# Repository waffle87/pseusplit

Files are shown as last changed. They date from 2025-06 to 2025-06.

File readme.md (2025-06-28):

# Pseusplit

A pseudo-split keyboard with a trackpad or LCD display and per-key RGB

pcb_top

pcb_bottom

## Hardware Specifics
This keyboard uses an integrated STM32G0B1 microcontroller fit with a single push button switch<sup>[1](#references)</sup>, and USB-C. It also features a dedicated IS31FL3733 RGB Matrix driver to alleviate processing power from the primary MCU for LCD drawing, or other tasks.

## Ordering
The following instructions will be for [JLCPCB](jlcpcb.com), but should generally apply to most PCB manufacturers. The Gerber files in this repository include:
- [**pcb_gerbers.zip**](production/pcb_gerbers.zip): Main PCB
- [**plate_gerbers.zip**](production/plate_gerbers.zip): Switch Plate PCB<sup>*</sup>
- [**back_gerbers.zip**](production/back_gerbers.zip): Backplate PCB

* The switch plate PCB is designed for a single half of the keyboard (and is reversible), meaning ordering a quantity of 10 will be enough to cover 5 keyboards.

1. Upload the appropriate Gerber files described above
2. Set PCB quantity and colour as desired
3. For PCB assembly, choose **Economic** PCBA type and **Bottom Side** for assembly side
4. Upload the [BOM](production/bom.csv) and [CPL](production/positions.csv) files
5. Ensure the correct components have been selected, and all are in stock. An effort has been made to choose as few extended components as possible, but this is not possible for some.
6. Give a quick look at the component placement and make sure nothing looks wildly wrong. It is normal for some components to be shown oriented incorrectly or not quite where they belong. The PCB reviewers will usually correct this without issue.

### Additional Components
For optional components to be installed by hand:
| Item | Quantity | Remarks |
|---|---|---|
| 6028 RGB LEDs ([Alibaba](https://www.alibaba.com/product-detail/smd-6028-RGB-led-diode-for_60637386884.html)) | 36 | Unforunately, LEDs matching this pinout are rather difficult to find, and are not carried by LCSC. |
| 4mm M2 Screws | 8 | Used for mounting PCB to plate case. Length does not have to be exact. |
| 6mm M2 Standoffs | 4 | Used for mounting PCB to plate case. Ensure maximum diameter is no greater than 4mm. |
| 240x240 LCD ([ST7789](https://www.adafruit.com/product/3787)) | 1<sup>*</sup> | Other displays with same pinout and dimensions (no larger than 40x43mm) will work. |
| Azoteq Trackpad ([TPS43](https://www.mouser.com/ProductDetail/Azoteq/TPS43-201A-B?qs=HXFqYaX1Q2x%252BNkQCZlM0ug%3D%3D)) | 1<sup>*</<sup> | Installed via soldering wires to appropriate display header pins. |
| MX Switches | 36 | Pick your favourite switches! |

* Trackpad and LCD is either/or. Both cannot be installed at the same time.

## Assembly Instructions
These steps assume you already have an assembled PCB and are installing switches, trackpad, etc. If you are hand-assembling the PCBs with all components, the [interactive BOM](https://html-preview.github.io/?url=https://github.com/waffle87/pseusplit/blob/master/ibom.html) will be handy.

1. **Compile and flash firmware.** This assumes a local QMK build environment has already been setup. Firmware sources can be found [here](https://git.pngu.org/qmk_me/keyboards/pseusplit). Enter bootloader by holding the reset button while plugging PCB in. Flash firmware using `qmk flash` or QMK Toolbox.
2. **Ensure the keyboard is functional** by shorting switch footprint pins with metal tweezers. This should output keypresses on the computer.
3. **Install LCD display if desired.** Solder the 12 pin header to the labeled footprint on the PCB and solder display to the header. In the firmware, enable the Quantum Painter feature and disable the Pointing Device feature if necessary.
4. **Install Azoteq trackpad if desired.** Solder wires from the pins on the trackpad to the appropriate pins on the 12 pin header. Refer to schematic for specifics. In the firmware, enable the Pointing Device feature and disable the Quantum Painter feature if necessary.
5. **Install switches** by inserting a few switches into the switch plate (corners/middle), and then solder to PCB. Fill in rest of switches, testing as you go.
6. **Assemble plate case**. Insert the M2 screws into the back plate and affix standoffs to screws. Place PCB + Plate onto standoffs and install remaining 4 screws.

## References
1. [A single-push reset circuit for STM32](https://acheronproject.com/reset_article_1/reset_article_1)
2. Relevant datasheets

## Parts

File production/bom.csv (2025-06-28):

Designator | Footprint | Quantity | Value | LCSC Part #
C1, C2, C4, C6 | 0805 | 4 | 0.47u | C13967
C10, C11 | 0805 | 2 | 1u | C28323
C12, C9 | 0805 | 2 | 4.7n | C1744
C13 | 0805 | 1 | 10u | C15850
C14, C16 | 0805 | 2 | 100n | C28233
C17, C18 | 0805 | 2 | 4.7u | C1779
C3, C5, C7 | 0805 | 3 | 0.1u | C49678
C8 | CP_EIA-3216-18_Kemet-A | 1 | 22u | C11366
D1, D10, D11, D12, D13, D14, D15, D16, D17, D18, D19, D2, D20, D21, D22, D23, D24, D25, D26, D27, D28, D29, D3, D30, D31, D32, D33, D34, D38, D39, D4, D5, D6, D7, D8, D9 | D_SOD-123 | 36 | D_45deg | C81598
D37 | D_SOD-123 | 1 | 1N4148 | C81598
D40 | 0805 | 1 | LED | C2297
F1 | 1206 | 1 | 500mA | C70070
J1 | USB_C_Receptacle_HRO_TYPE-C-31-M-12 | 1 | USB_C_Receptacle_USB2.0_14P | C165948
Q1 | SOT-23 | 1 | DTC123J | C406040
R1 | 0805 | 1 | 20k | C4328
R11, R2 | 0805 | 2 | 100k | C149504
R12, R7, R8 | 0805 | 3 | 5.1k | C27834
R3 | 0805 | 1 | 10k | C17414
R4, R5 | 0805 | 2 | 2k | C17604
R6 | 0805 | 1 | 1M | C17514
SW1 | SW_SPST_SKQG_WithStem | 1 | Reset_SW | C318884
U1 | QFN-48-1EP_6x6mm_P0.4mm_EP4.2x4.2mm | 1 | IS31FL3733-QF | C506251
U2 | SOT-23-3 | 1 | XC6206PxxxMR | C5446
U4 | LQFP-48_7x7mm_P0.5mm | 1 | STM32G0B1CBTx | C2847904
U5 | SOT-23-6-routable | 1 | SRV05-4 | C558418

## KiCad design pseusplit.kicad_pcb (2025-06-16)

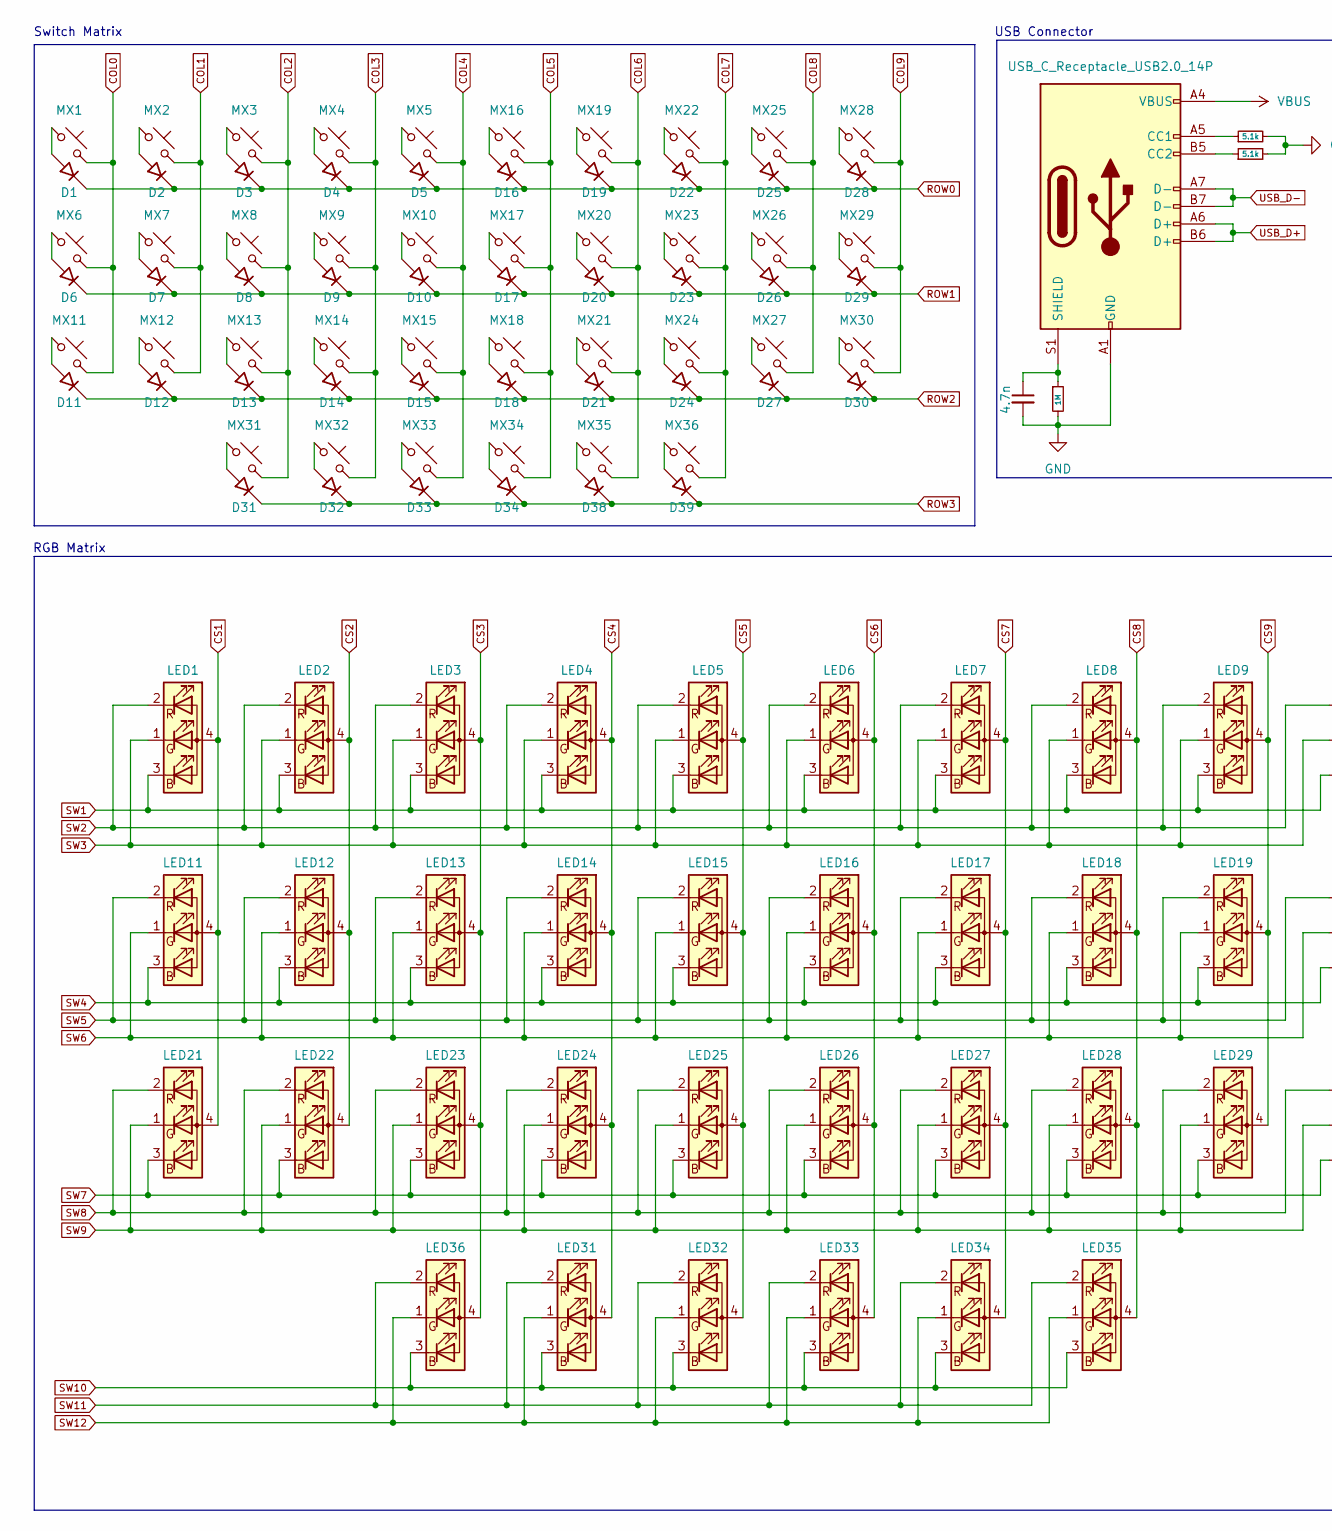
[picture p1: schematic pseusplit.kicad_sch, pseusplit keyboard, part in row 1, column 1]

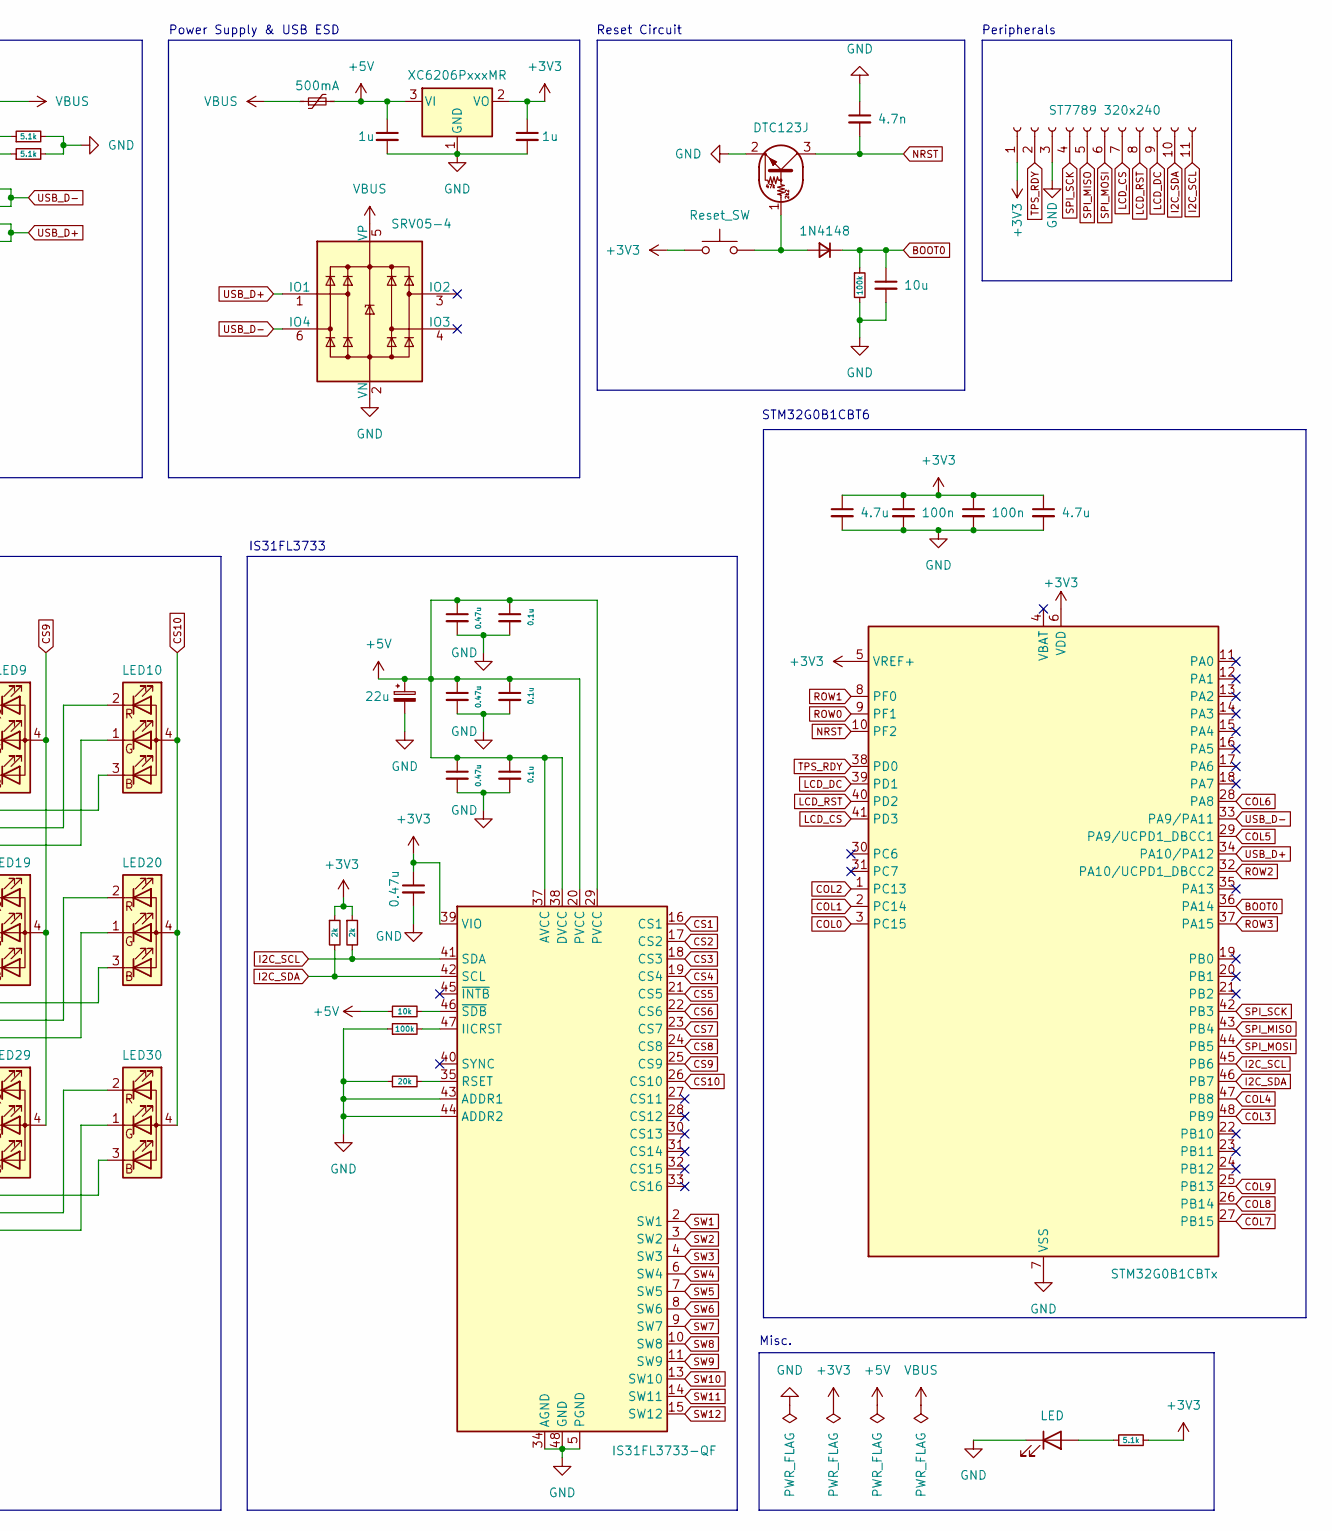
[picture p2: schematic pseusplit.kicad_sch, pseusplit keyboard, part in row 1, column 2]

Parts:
C1, C2, C4, C6: 0.47u; C_0805_2012Metric; MPN C13967
C3, C5, C7: 0.1u; C_0805_2012Metric; MPN C49678
C8: 22u; C_0805_2012Metric; MPN C45783
C9, C12: 4.7n; C_0805_2012Metric; MPN C1744
C10, C11: 1u; C_0805_2012Metric; MPN C28323
C13: 10u; C_0805_2012Metric; MPN C15850
C14, C16: 100n; C_0805_2012Metric; MPN C28233
C17, C18: 4.7u; C_0805_2012Metric; MPN C1779
D1, D2, D3, D4, D5, D6, D7, D8, D9, D10, D11, D12, D13, D14, D15, D16, D17, D18, D19, D20, D21, D22, D23, D24, D25, D26, D27, D28, D29, D30, D31, D32, D33, D34, D38, D39: D_45deg; D_SOD-123; MPN C81598
D37: 1N4148; D_SOD-123; MPN C81598
D40: LED; LED_0805_2012Metric; MPN C2297
F1: 500mA; Fuse_1206_3216Metric; MPN C2830238
J1: USB_C_Receptacle_USB2.0_14P; USB_C_Receptacle_HRO_TYPE-C-31-M-12; MPN C165948
J3: ST7789 320x240; PinHeader_1x11_P2.54mm_Vertical
LED1, LED2, LED3, LED4, LED5, LED6, LED7, LED8, LED9, LED10, LED11, LED12, LED13, LED14, LED15, LED16, LED17, LED18, LED19, LED20, LED21, LED22, LED23, LED24, LED25, LED26, LED27, LED28, LED29, LED30, LED31, LED32, LED33, LED34, LED35, LED36: MX_LED_6028R; LED_MX_6028R; MPN C183826
MX1: Q; SW_MX_1u
MX2: W; SW_MX_1u
MX3: E; SW_MX_1u
MX4: R; SW_MX_1u
MX5: T; SW_MX_1u
MX6: A; SW_MX_1u
MX7: S; SW_MX_1u
MX8: D; SW_MX_1u
MX9: F; SW_MX_1u
MX10: G; SW_MX_1u
MX11: Z; SW_MX_1u
MX12: X; SW_MX_1u
MX13: C; SW_MX_1u
MX14: V; SW_MX_1u
MX15: B; SW_MX_1u
MX16: Y; SW_MX_1u
MX17: H; SW_MX_1u
MX18: N; SW_MX_1u
MX19: U; SW_MX_1u
MX20: J; SW_MX_1u
MX21: M; SW_MX_1u
MX22: I; SW_MX_1u
MX23: K; SW_MX_1u
MX24: ,; SW_MX_1u
MX25: O; SW_MX_1u
MX26: L; SW_MX_1u
MX27: .; SW_MX_1u
MX28: P; SW_MX_1u
MX29: ;; SW_MX_1u
MX30: /; SW_MX_1u
MX31: T1; SW_MX_1u
MX32: T2; SW_MX_1u
MX33: T3; SW_MX_1u
MX34: T4; SW_MX_1u
MX35: T5; SW_MX_1u
MX36: T6; SW_MX_1u
Q1: DTC123J; SOT-23; MPN C20616358
R1: 20k; R_0805_2012Metric; MPN C4328
R2, R11: 100k; R_0805_2012Metric; MPN C149504
R3: 10k; R_0805_2012Metric; MPN C17414
R4, R5: 2k; R_0805_2012Metric; MPN C17604
R6: 1M; R_0805_2012Metric; MPN C17514
R7, R8, R12: 5.1k; R_0805_2012Metric; MPN C27834
SW1: Reset_SW; SW_SPST_SKQG_WithStem; MPN C318884
U1: IS31FL3733-QF; QFN-48-1EP_6x6mm_P0.4mm_EP4.2x4.2mm; MPN C506251
U2: XC6206PxxxMR; SOT-23-3; MPN C5446
U4: STM32G0B1CBTx; LQFP-48_7x7mm_P0.5mm; MPN C2847904
U5: SRV05-4; SOT-23-6-routable; MPN C558418

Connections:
+3V3: C1.1, C11.1, C14.1, C16.1, C17.1, C18.1, J3.1, R4.1, R5.1, R12.2, SW1.1, U1.39 (VIO), U2.2 (VO), U4.5 (VREF+), U4.6 (VDD)
+5V: C2.1, C3.1, C4.1, C5.1, C6.1, C7.1, C8.1, C10.1, F1.2, R3.1, U1.20 (PVCC), U1.29 (PVCC), U1.37 (AVCC), U1.38 (DVCC), U2.3 (VI)
BOOT0: C13.1, D37.1 (K), R11.1, U4.36 (PA14)
COL0: MX1.2, MX6.2, MX11.2, U4.3 (PC15)
COL1: MX2.2, MX7.2, MX12.2, U4.2 (PC14)
COL2: MX3.2, MX8.2, MX13.2, MX31.2, U4.1 (PC13)
COL3: MX4.2, MX9.2, MX14.2, MX32.2, U4.48 (PB9)
COL4: MX5.2, MX10.2, MX15.2, MX33.2, U4.47 (PB8)
COL5: MX16.2, MX17.2, MX18.2, MX34.2, U4.29 (PA9/UCPD1_DBCC1)
COL6: MX19.2, MX20.2, MX21.2, MX35.2, U4.28 (PA8)
COL7: MX22.2, MX23.2, MX24.2, MX36.2, U4.27 (PB15)
COL8: MX25.2, MX26.2, MX27.2, U4.26 (PB14)
COL9: MX28.2, MX29.2, MX30.2, U4.25 (PB13)
CS1: LED1.4 (A), LED11.4 (A), LED21.4 (A), U1.16 (CS1)
CS2: LED2.4 (A), LED12.4 (A), LED22.4 (A), U1.17 (CS2)
CS3: LED3.4 (A), LED13.4 (A), LED23.4 (A), LED36.4 (A), U1.18 (CS3)
CS4: LED4.4 (A), LED14.4 (A), LED24.4 (A), LED31.4 (A), U1.19 (CS4)
CS5: LED5.4 (A), LED15.4 (A), LED25.4 (A), LED32.4 (A), U1.21 (CS5)
CS6: LED6.4 (A), LED16.4 (A), LED26.4 (A), LED33.4 (A), U1.22 (CS6)
CS7: LED7.4 (A), LED17.4 (A), LED27.4 (A), LED34.4 (A), U1.23 (CS7)
CS8: LED8.4 (A), LED18.4 (A), LED28.4 (A), LED35.4 (A), U1.24 (CS8)
CS9: LED9.4 (A), LED19.4 (A), LED29.4 (A), U1.25 (CS9)
CS10: LED10.4 (A), LED20.4 (A), LED30.4 (A), U1.26 (CS10)
GND: C1.2, C2.2, C3.2, C4.2, C5.2, C6.2, C7.2, C8.2, C9.2, C10.2, C11.2, C12.1, C13.2, C14.2, C16.2, C17.2, C18.2, D40.1 (K), J1.A1 (GND), J1.A12 (GND), J1.B1 (GND), J1.B12 (GND), J3.3, Q1.2 (E), R1.1, R2.1, R6.2, R7.2, R8.2, R11.2, U1.5 (PGND), U1.12 (PGND), U1.34 (AGND), U1.43 (ADDR1), U1.44 (ADDR2), U1.48 (GND), U1.49 (GND), U2.1 (GND), U4.7 (VSS), U5.2 (VN)
I2C_SCL: J3.11, R5.2, U1.41 (SDA), U4.45 (PB6)
I2C_SDA: J3.10, R4.2, U1.42 (SCL), U4.46 (PB7)
LCD_CS: J3.7, U4.41 (PD3)
LCD_DC: J3.9, U4.39 (PD1)
LCD_RST: J3.8, U4.40 (PD2)
NRST: C12.2, Q1.3 (C), U4.10 (PF2)
unnamed: D1.2 (A), MX1.1
unnamed: D2.2 (A), MX2.1
unnamed: D3.2 (A), MX3.1
unnamed: D4.2 (A), MX4.1
unnamed: D5.2 (A), MX5.1
unnamed: D6.2 (A), MX6.1
unnamed: D7.2 (A), MX7.1
unnamed: D8.2 (A), MX8.1
unnamed: D9.2 (A), MX9.1
unnamed: D10.2 (A), MX10.1
unnamed: D11.2 (A), MX11.1
unnamed: D12.2 (A), MX12.1
unnamed: D13.2 (A), MX13.1
unnamed: D14.2 (A), MX14.1
unnamed: D15.2 (A), MX15.1
unnamed: D16.2 (A), MX16.1
unnamed: D17.2 (A), MX17.1
unnamed: D18.2 (A), MX18.1
unnamed: D19.2 (A), MX19.1
unnamed: D20.2 (A), MX20.1
unnamed: D21.2 (A), MX21.1
unnamed: D22.2 (A), MX22.1
unnamed: D23.2 (A), MX23.1
unnamed: D24.2 (A), MX24.1
unnamed: D25.2 (A), MX25.1
unnamed: D26.2 (A), MX26.1
unnamed: D27.2 (A), MX27.1
unnamed: D28.2 (A), MX28.1
unnamed: D29.2 (A), MX29.1
unnamed: D30.2 (A), MX30.1
unnamed: D31.2 (A), MX31.1
unnamed: D32.2 (A), MX32.1
unnamed: D33.2 (A), MX33.1
unnamed: D34.2 (A), MX34.1
unnamed: D37.2 (A), Q1.1 (B), SW1.2
unnamed: D38.2 (A), MX35.1
unnamed: D39.2 (A), MX36.1
unnamed: D40.2 (A), R12.1
unnamed: J1.A5 (CC1), R7.1
unnamed: J1.B5 (CC2), R8.1
unnamed: C9.1, J1.S1 (SHIELD), R6.1
unnamed: R2.2, U1.47 (IICRST)
unnamed: R1.2, U1.35 (RSET)
unnamed: R3.2, U1.46 (~SDB)
ROW0: D1.1 (K), D2.1 (K), D3.1 (K), D4.1 (K), D5.1 (K), D16.1 (K), D19.1 (K), D22.1 (K), D25.1 (K), D28.1 (K), U4.9 (PF1)
ROW1: D6.1 (K), D7.1 (K), D8.1 (K), D9.1 (K), D10.1 (K), D17.1 (K), D20.1 (K), D23.1 (K), D26.1 (K), D29.1 (K), U4.8 (PF0)
ROW2: D11.1 (K), D12.1 (K), D13.1 (K), D14.1 (K), D15.1 (K), D18.1 (K), D21.1 (K), D24.1 (K), D27.1 (K), D30.1 (K), U4.32 (PA10/UCPD1_DBCC2)
ROW3: D31.1 (K), D32.1 (K), D33.1 (K), D34.1 (K), D38.1 (K), D39.1 (K), U4.37 (PA15)
SPI_MISO: J3.5, U4.43 (PB4)
SPI_MOSI: J3.6, U4.44 (PB5)
SPI_SCK: J3.4, U4.42 (PB3)
SW1: LED1.3 (BK), LED2.3 (BK), LED3.3 (BK), LED4.3 (BK), LED5.3 (BK), LED6.3 (BK), LED7.3 (BK), LED8.3 (BK), LED9.3 (BK), LED10.3 (BK), U1.2 (SW1)
SW2: LED1.2 (RK), LED2.2 (RK), LED3.2 (RK), LED4.2 (RK), LED5.2 (RK), LED6.2 (RK), LED7.2 (RK), LED8.2 (RK), LED9.2 (RK), LED10.2 (RK), U1.3 (SW2)
SW3: LED1.1 (GK), LED2.1 (GK), LED3.1 (GK), LED4.1 (GK), LED5.1 (GK), LED6.1 (GK), LED7.1 (GK), LED8.1 (GK), LED9.1 (GK), LED10.1 (GK), U1.4 (SW3)
SW4: LED11.3 (BK), LED12.3 (BK), LED13.3 (BK), LED14.3 (BK), LED15.3 (BK), LED16.3 (BK), LED17.3 (BK), LED18.3 (BK), LED19.3 (BK), LED20.3 (BK), U1.6 (SW4)
SW5: LED11.2 (RK), LED12.2 (RK), LED13.2 (RK), LED14.2 (RK), LED15.2 (RK), LED16.2 (RK), LED17.2 (RK), LED18.2 (RK), LED19.2 (RK), LED20.2 (RK), U1.7 (SW5)
SW6: LED11.1 (GK), LED12.1 (GK), LED13.1 (GK), LED14.1 (GK), LED15.1 (GK), LED16.1 (GK), LED17.1 (GK), LED18.1 (GK), LED19.1 (GK), LED20.1 (GK), U1.8 (SW6)
SW7: LED21.3 (BK), LED22.3 (BK), LED23.3 (BK), LED24.3 (BK), LED25.3 (BK), LED26.3 (BK), LED27.3 (BK), LED28.3 (BK), LED29.3 (BK), LED30.3 (BK), U1.9 (SW7)
SW8: LED21.2 (RK), LED22.2 (RK), LED23.2 (RK), LED24.2 (RK), LED25.2 (RK), LED26.2 (RK), LED27.2 (RK), LED28.2 (RK), LED29.2 (RK), LED30.2 (RK), U1.10 (SW8)
SW9: LED21.1 (GK), LED22.1 (GK), LED23.1 (GK), LED24.1 (GK), LED25.1 (GK), LED26.1 (GK), LED27.1 (GK), LED28.1 (GK), LED29.1 (GK), LED30.1 (GK), U1.11 (SW9)
SW10: LED31.3 (BK), LED32.3 (BK), LED33.3 (BK), LED34.3 (BK), LED35.3 (BK), LED36.3 (BK), U1.13 (SW10)
SW11: LED31.2 (RK), LED32.2 (RK), LED33.2 (RK), LED34.2 (RK), LED35.2 (RK), LED36.2 (RK), U1.14 (SW11)
SW12: LED31.1 (GK), LED32.1 (GK), LED33.1 (GK), LED34.1 (GK), LED35.1 (GK), LED36.1 (GK), U1.15 (SW12)
TPS_RDY: J3.2, U4.38 (PD0)
USB_D+: J1.A6 (D+), J1.B6 (D+), U4.34 (PA10/PA12), U5.1 (IO1)
USB_D-: J1.A7 (D-), J1.B7 (D-), U4.33 (PA9/PA11), U5.6 (IO4)
VBUS: F1.1, J1.A4 (VBUS), J1.A9 (VBUS), J1.B4 (VBUS), J1.B9 (VBUS), U5.5 (VP)

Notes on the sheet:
IS31FL3733
RGB Matrix
STM32G0B1CBT6
Power Supply & USB ESD
USB Connector
Misc.
Reset Circuit
Switch Matrix
Peripherals

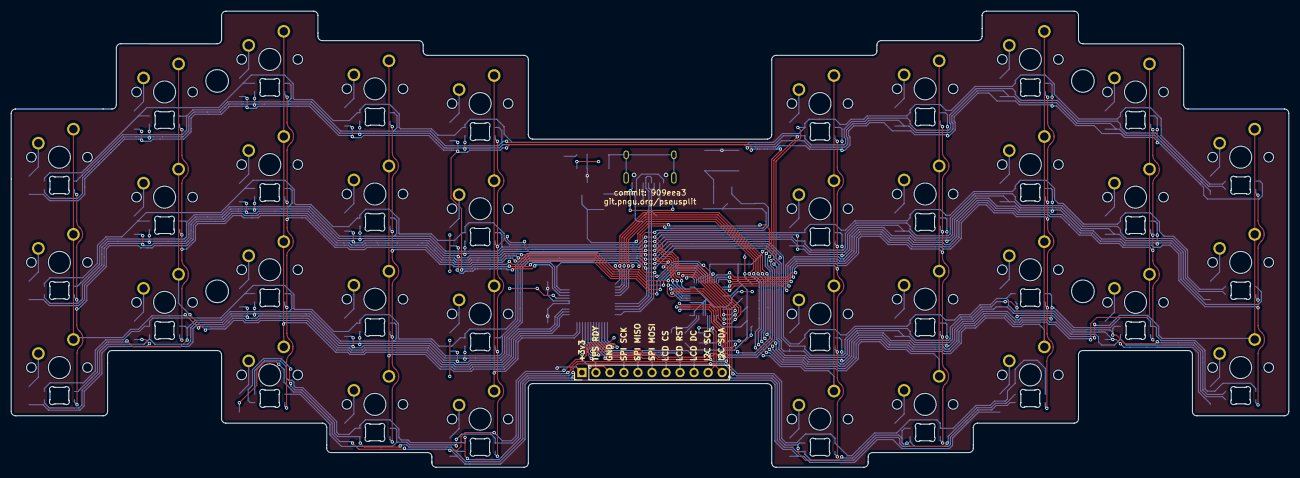
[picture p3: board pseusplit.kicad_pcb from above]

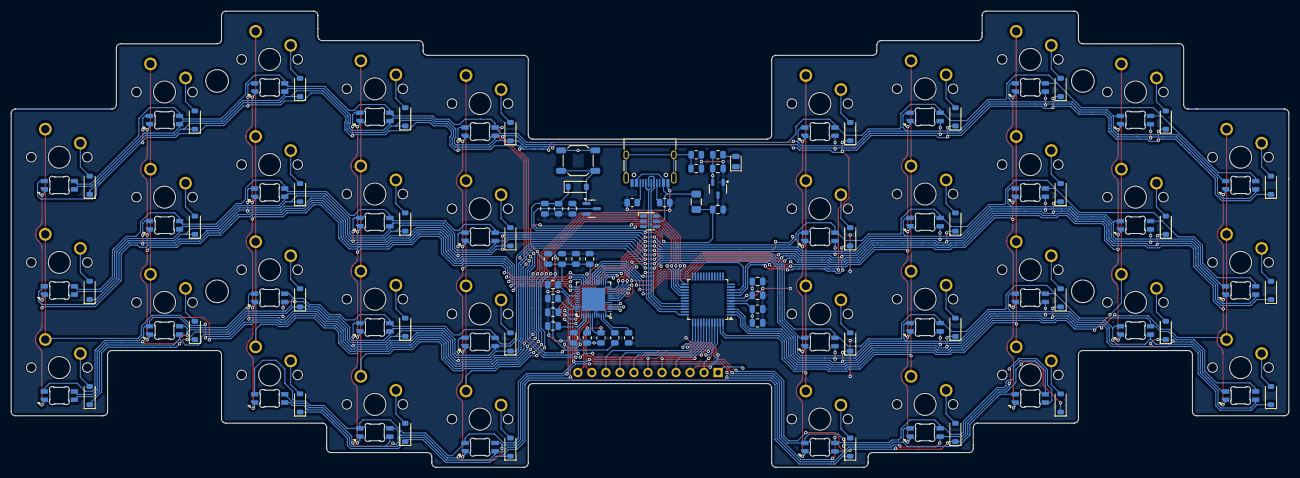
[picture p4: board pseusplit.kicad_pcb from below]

Board: 2 copper layers, 231.4 x 82.6 mm, 146 parts (109 on the bottom side), 97 nets.

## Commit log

2025-06-16 Add PCBs (eletronic, backplate, switchplate), production files, and initial documentation
    [back.kicad_pcb, bom.csv, plate.kicad_pcb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]
2025-06-16 Add silkscreen graphics and SVG images
    [pseusplit.kicad_pcb]
2025-06-16 Update some part numbers, remove unnecessary MPN symbol field, dos2unix CSV files
    [bom.csv, positions.csv, pseusplit.kicad_sch]
2025-06-27 Update tantalum capacitor footprint & part, remove LEDs from BOM & provide link
    [bom.csv, positions.csv, pseusplit.kicad_sch]
2025-06-27 Update silkscreen graphics, IBOM, gerbers, and readme typo
2025-06-28 Some readme fixes and correct part number from SOT-523 -> SOT23
    [bom.csv]
